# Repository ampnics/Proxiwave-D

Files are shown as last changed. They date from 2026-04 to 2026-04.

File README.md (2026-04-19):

# ProxiWave-D (PWD-v010A)
### Touchless Proximity-Based AC Relay Controller — Open Source Hardware by Ampnics







> An open-source, touchless proximity-based AC relay controller built on ATmega328-A with a VL53L0X Time-of-Flight sensor — designed for contactless switching of 220VAC loads by detecting hand proximity within 10–30mm range.

---

## 📸 Board Preview

| PCB Top View (Sensor Side) | PCB Bottom View (Power Side) |



---


---

## 📋 Table of Contents

- [Overview](#-overview)
- [Features](#-features)
- [How It Works](#-how-it-works)
- [Hardware Specifications](#-hardware-specifications)
- [GPIO Mapping](#-gpio-mapping)
- [Pin Description](#-pin-description)
- [Repository Structure](#-repository-structure)
- [Getting Started](#-getting-started)
- [Firmware Setup](#-firmware-setup)
- [Calibration](#-calibration)
- [Manufacturing](#-manufacturing)
- [Safety Warning](#️-safety-warning)
- [Contributing](#-contributing)
- [Support Us](#-support-us)
- [Connect With Us](#-connect-with-us)
- [License](#-license)

---

## 🔍 Overview

The **ProxiWave-D** is an open-source, touchless proximity relay controller designed for contactless switching of 220VAC loads. It uses a **VL53L0X Time-of-Flight (ToF) distance sensor** to detect hand proximity within a calibrated range of **10mm to 30mm**, triggering an onboard relay to switch AC loads — no physical contact required.

The board runs on **220VAC mains input**, converting it to **5V DC** via an onboard HLK-5M05 power supply module, and further to **3.3V** via an AMS1117-3.3 LDO — powering the ATmega328 and the VL53L0X sensor.

A **backup IR sensor connector (J3)** is also provided for redundancy or alternative sensing modes.

Designed in **KiCad 9.0.1** as part of the open-source hardware series by Ampnics.

---

## ✨ Features

- ✅ Touchless relay switching via VL53L0X ToF proximity sensor
- ✅ ATmega328-A microcontroller (8MHz crystal, 3.3V operation)
- ✅ 220VAC to 5VDC onboard power supply (HLK-5M05)
- ✅ 5V to 3.3V LDO regulator (AMS1117-3.3)
- ✅ SPDT relay for AC load switching
- ✅ MOV surge protection (10D561K)
- ✅ Fuse protection (0.5A / 250VAC)
- ✅ Backup IR sensor connector (J3)
- ✅ Buzzer feedback (MLT-8530)
- ✅ Power LED (Red) + Relay LED (Blue) + Status LED (Green)
- ✅ ICSP / SPI programming port (J2 — 2x3 header)
- ✅ Reset button (SW1)
- ✅ 5x screw terminal AC connector (J1)
- ✅ Test points — 5V, 3V3, GND, AVDD
- ✅ Fiducial markers + 4x mounting holes
- ✅ Sensing area clearly marked on PCB silkscreen
- ✅ Fully open-source — KiCad files included

---

## 🔄 How It Works

```
Hand approaches sensing area (10mm–30mm range)
              │
              ▼
   VL53L0X ToF Sensor detects distance
              │
              ▼
   ATmega328 reads I2C data from sensor
              │
              ▼
   Distance within calibrated threshold?
         ┌────┴────┐
        YES        NO
         │          │
         ▼          ▼
   Relay toggles  No action
   AC load ON/OFF
         │
         ▼
   Buzzer beeps + Status LED updates
```

---

## 🔧 Hardware Specifications

| Parameter | Details |
|---|---|
| Microcontroller | ATmega328-A |
| MCU Clock | 8MHz (External Crystal Y1) |
| MCU Operating Voltage | 3.3V |
| Proximity Sensor | VL53L0X ToF (I2C) |
| Sensor Operating Voltage | 2.6V – 3.6V (3.3V) |
| Detection Range | 10mm – 30mm (calibrated) |
| Input Voltage | 220V AC |
| Power Supply Module | HLK-5M05 (220VAC → 5VDC) |
| LDO Regulator | AMS1117-3.3 (5V → 3.3V) |
| Relay | G5LE-1 (SPDT) |
| Surge Protection | MOV 10D561K |
| Fuse | 0.5A / 250VAC |
| Buzzer | MLT-8530 |
| Status LEDs | Red (Power), Blue (Relay), Green (Status) |
| Programming | ICSP / SPI (J2 — 2x3 header) |
| Backup Sensor Port | J3 — 3-pin connector |
| PCB Tool | KiCad 9.0.1 |
| Board Revision | PWD-v010A |

---

## 📌 GPIO Mapping

| GPIO | Label | Function |
|---|---|---|
| PC1 / A1 | RIN / STS | Status indication |
| PC2 / A2 | RLY | Relay control |
| PC3 / A3 | BUZZER | Buzzer (MLT-8530) |
| PC4 / A4 | SDA | VL53L0X I2C SDA |
| PC5 / A5 | SCL | VL53L0X I2C SCL |
| PD2 / D2 | XSHUT | VL53L0X shutdown pin |
| PD4 / D4 | IR-BKP | Backup IR sensor (J3) |

---

## 🔌 Pin Description

### J1 — AC Screw Terminal (5-pin)

| Pin | Label | Description |
|---|---|---|
| 1 | AC/L | AC Line (Live) input |
| 2 | AC/N | AC Neutral input |
| 3 | NO | Relay Normally Open |
| 4 | C | Relay Common |
| 5 | NC | Relay Normally Closed |

### J2 — ICSP Programming Port (2x3)

| Pin | Label | Description |
|---|---|---|
| 1 | MISO | SPI MISO |
| 2 | VCC | 5V |
| 3 | SCK | SPI Clock |
| 4 | MOSI | SPI MOSI |
| 5 | RST | Reset |
| 6 | GND | Ground |

### J3 — Backup IR Sensor (3-pin)

| Pin | Label | Description |
|---|---|---|
| 1 | SIG | IR sensor signal |
| 2 | GND | Ground |
| 3 | 5V | Power |

### Signal Connector (3-pin)

| Pin | Label | Description |
|---|---|---|
| 1 | SIG | Signal output |
| 2 | GND | Ground |
| 3 | 3V3 | 3.3V output |

---

## 📁 Repository Structure

```
ProxiWave-D/
├── docs/                    # Datasheets and reference documents
├── imgs/                    # PCB renders and product images
├── manufacturing-files/     # Gerbers, BOM, CPL for fabrication
├── schematic/               # KiCad schematic & PCB files
├── ext-3d-models/           # External 3D models for KiCad
├── ext-lib/                 # External KiCad footprints & symbols
└── README.md
```

---

## 🚀 Getting Started

### Prerequisites
- [KiCad 9.0.1](https://www.kicad.org/) — to open schematic and PCB files
- [Arduino IDE](https://www.arduino.cc/en/software) — for firmware
- USBasp / AVRISP programmer — for flashing ATmega328
- [VL53L0X Arduino Library](https://github.com/pololu/vl53l0x-arduino)

### Clone the Repository
```bash
git clone https://github.com/ampnics/Proxiwave-D.git
cd Proxiwave-D
```

---

## 💻 Firmware Setup

### 1. Add ATmega328 (3.3V / 8MHz) Board Support

In Arduino IDE → **Preferences** → Additional Boards Manager URLs → add:
```
https://raw.githubusercontent.com/MCUdude/MiniCore/master/package_MCUdude_MiniCore_index.json
```
Then: **Tools → Board → Boards Manager → search "MiniCore" → Install**

Select these settings:
- Board: `ATmega328`
- Clock: `External 8MHz`
- Voltage: `3.3V`

### 2. Install Required Libraries
```
VL53L0X    → by Pololu
Wire       → built-in
```

### 3. Basic Firmware Structure

```cpp
#include <Wire.h>
#include <VL53L0X.h>

#define RELAY_PIN   A2   // PC2
#define BUZZER_PIN  A3   // PC3
#define XSHUT_PIN   2    // PD2
#define STATUS_PIN  A1   // PC1

#define MIN_RANGE   10   // mm
#define MAX_RANGE   30   // mm

VL53L0X sensor;

void setup() {
  pinMode(RELAY_PIN, OUTPUT);
  pinMode(BUZZER_PIN, OUTPUT);
  pinMode(XSHUT_PIN, OUTPUT);
  pinMode(STATUS_PIN, OUTPUT);

  digitalWrite(XSHUT_PIN, HIGH);
  Wire.begin();
  sensor.init();
  sensor.setTimeout(500);
  sensor.startContinuous();
}

void loop() {
  uint16_t distance = sensor.readRangeContinuousMillimeters();

  if (distance >= MIN_RANGE && distance <= MAX_RANGE) {
    digitalWrite(RELAY_PIN, !digitalRead(RELAY_PIN)); // Toggle relay
    digitalWrite(BUZZER_PIN, HIGH);
    delay(100);
    digitalWrite(BUZZER_PIN, LOW);
    delay(500); // Debounce delay
  }
}
```

### 4. Flash Using USBasp (ICSP)
```
Tools → Programmer → USBasp
Tools → Burn Bootloader (first time only)
Sketch → Upload Using Programmer
```

---

## 🎯 Calibration

> The VL53L0X sensor **must be calibrated** for reliable touchless operation.

- Default detection range: **10mm – 30mm**
- Adjust `MIN_RANGE` and `MAX_RANGE` in firmware based on your enclosure depth
- Mount sensor so the **sensing area circle** marked on PCB silkscreen is fully exposed
- Avoid reflective surfaces directly behind the sensing area
- Test under ambient light conditions before final deployment

---

## 🏭 Manufacturing

Fabrication files are available in `manufacturing-files/`:

- **Gerber files** — for PCB fabrication (JLCPCB / PCBWay)
- **BOM** — Bill of Materials with part numbers
- **CPL** — Component Placement List for SMT assembly

| Parameter | Value |
|---|---|
| Layers | 2 |
| Board Thickness | 1.6mm |
| Copper Weight | 1oz |
| Surface Finish | HASL / ENIG |
| Min Trace Width | 0.2mm |

---

## ⚠️ Safety Warning

> **This board operates at 220V AC mains voltage.**

- ⚠️ Do **NOT** touch the board while connected to mains power
- ⚠️ AC and DC sections are separated on the PCB — always respect this boundary
- ⚠️ Always use proper insulation and an enclosure before deployment
- ⚠️ Fuse (F1 — 0.5A/250VAC) must always be populated
- ⚠️ Intended for use by qualified engineers only

---

## 🤝 Contributing

Contributions are welcome from the community!

1. Fork the repository
2. Create your branch: `git checkout -b feature/your-feature`
3. Commit: `git commit -m "hw: your change"`
4. Push: `git push origin feature/your-feature`
5. Open a **Pull Request**

---

## ☕ Support Us

If this project helped you, consider buying us a coffee!

**[☕ Buy Me a Coffee — Support Ampnics](https://buymeacoffee.com/Ampnics)**

Your support helps us create more open-source hardware for the community!

---

## 🌐 Connect With Us

| Platform | Link |
|---|---|
| 📺 YouTube | [youtube.com/@ampnics](https://youtube.com/@ampnics?si=e0dvaRhfExjZXtJc) |
| 📸 Instagram | [instagram.com/ampnics](https://www.instagram.com/ampnics/) |
| 🐦 X (Twitter) | [twitter.com/ampnics](https://twitter.com/ampnics) |
| 💼 LinkedIn | [linkedin.com/company/ampnics](https://www.linkedin.com/company/ampnics/) |
| 🐙 GitHub | [github.com/ampnics](https://github.com/ampnics) |
| 💬 WhatsApp Community | [Join Here](https://chat.whatsapp.com/HgWOoxyOgLfGEkAPHPM01k) |
| 🌐 Website | [ampnics.com](https://ampnics.com) |

---

## 📄 License

This project is licensed under the **MIT License**.

You are free to use, modify, and distribute this design for personal and commercial purposes with attribution.

---

## 👨‍💻 Designed By

**Md Ammar Maniyar** — [Ampnics](https://github.com/ampnics)

*Engineered in India 🇮🇳*

---

⭐ **Star this repo** if it helped you — it motivates us to release more open-source hardware!

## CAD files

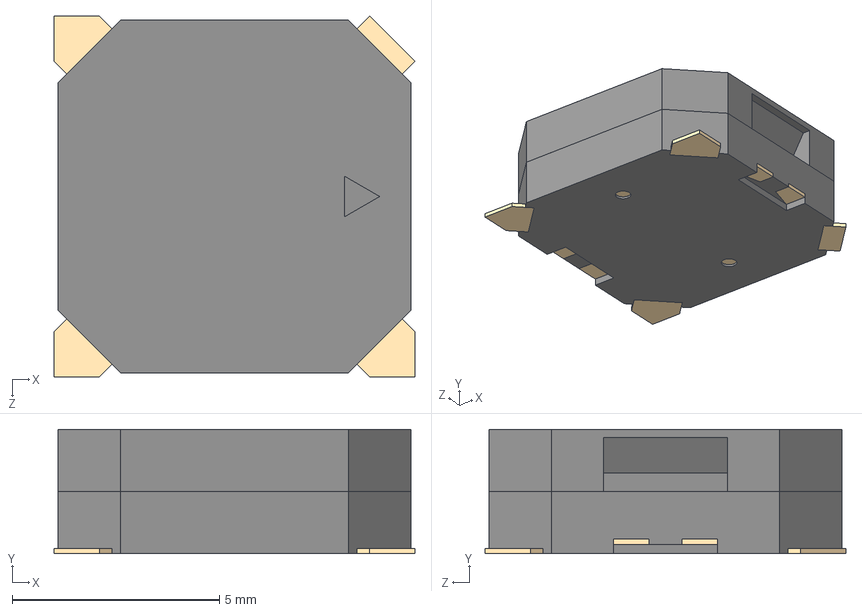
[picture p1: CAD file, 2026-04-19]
Hardware/PWD-v010A/3D-MODELS/MLT-8530--3DModel-STEP-269445.STEP
8.70 x 3.00 x 8.70 mm

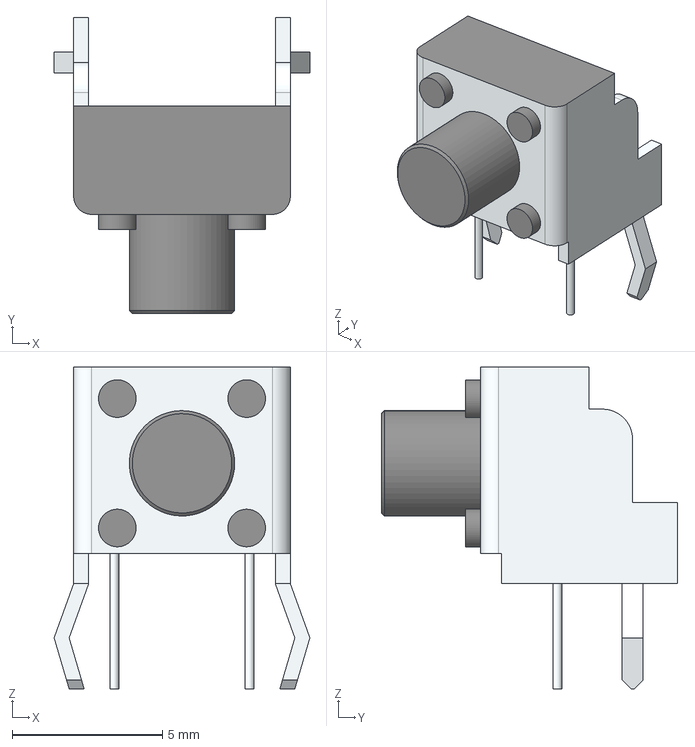
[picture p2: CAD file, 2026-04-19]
Hardware/PWD-v010A/3D-MODELS/SW-DTSA-63K-V.stp
8.50 x 9.85 x 10.7 mm

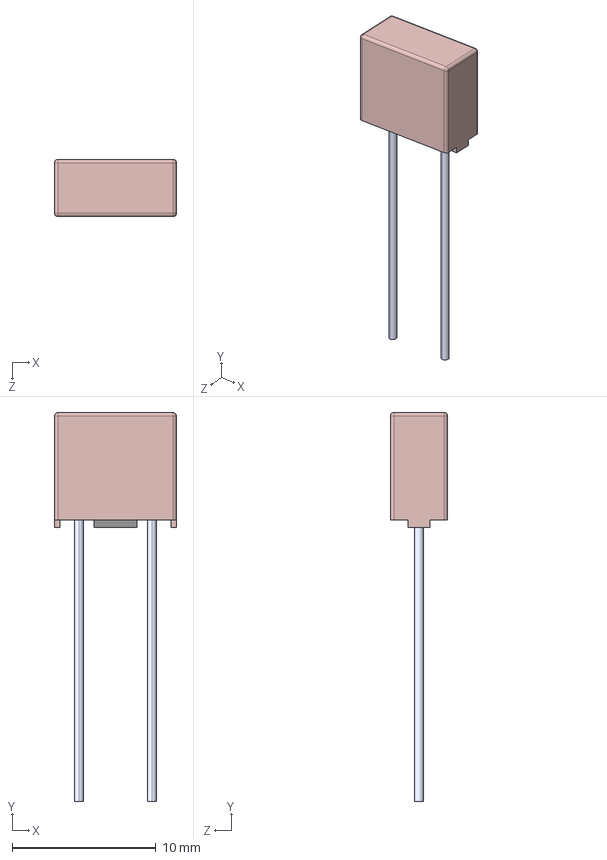
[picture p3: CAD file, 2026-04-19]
Hardware/PWD-v010A/3D-MODELS/39208000000.STEP
8.50 x 27.1 x 4.00 mm

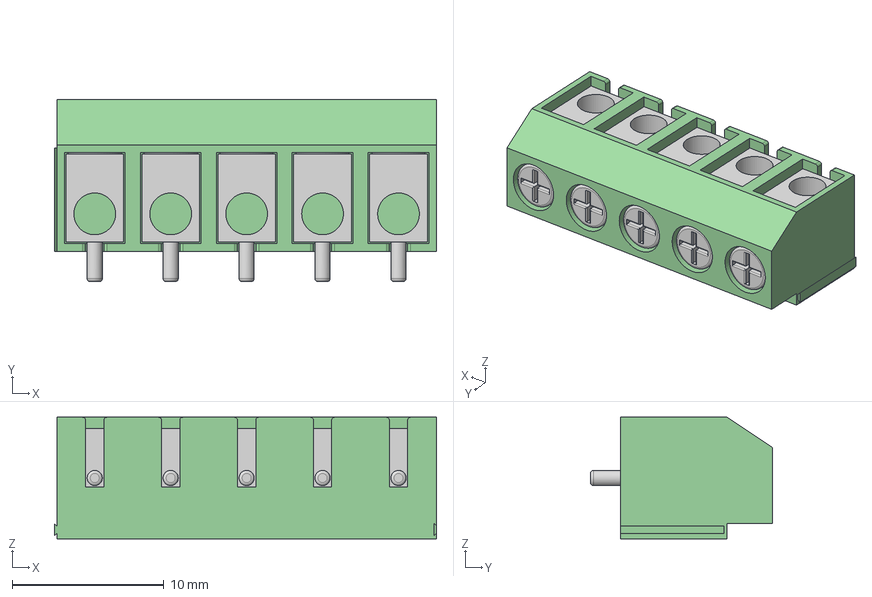
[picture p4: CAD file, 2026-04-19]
Hardware/PWD-v010A/3D-MODELS/Screw Terminal Block 5mm 5-way.step
25.1 x 12.0 x 8.00 mm

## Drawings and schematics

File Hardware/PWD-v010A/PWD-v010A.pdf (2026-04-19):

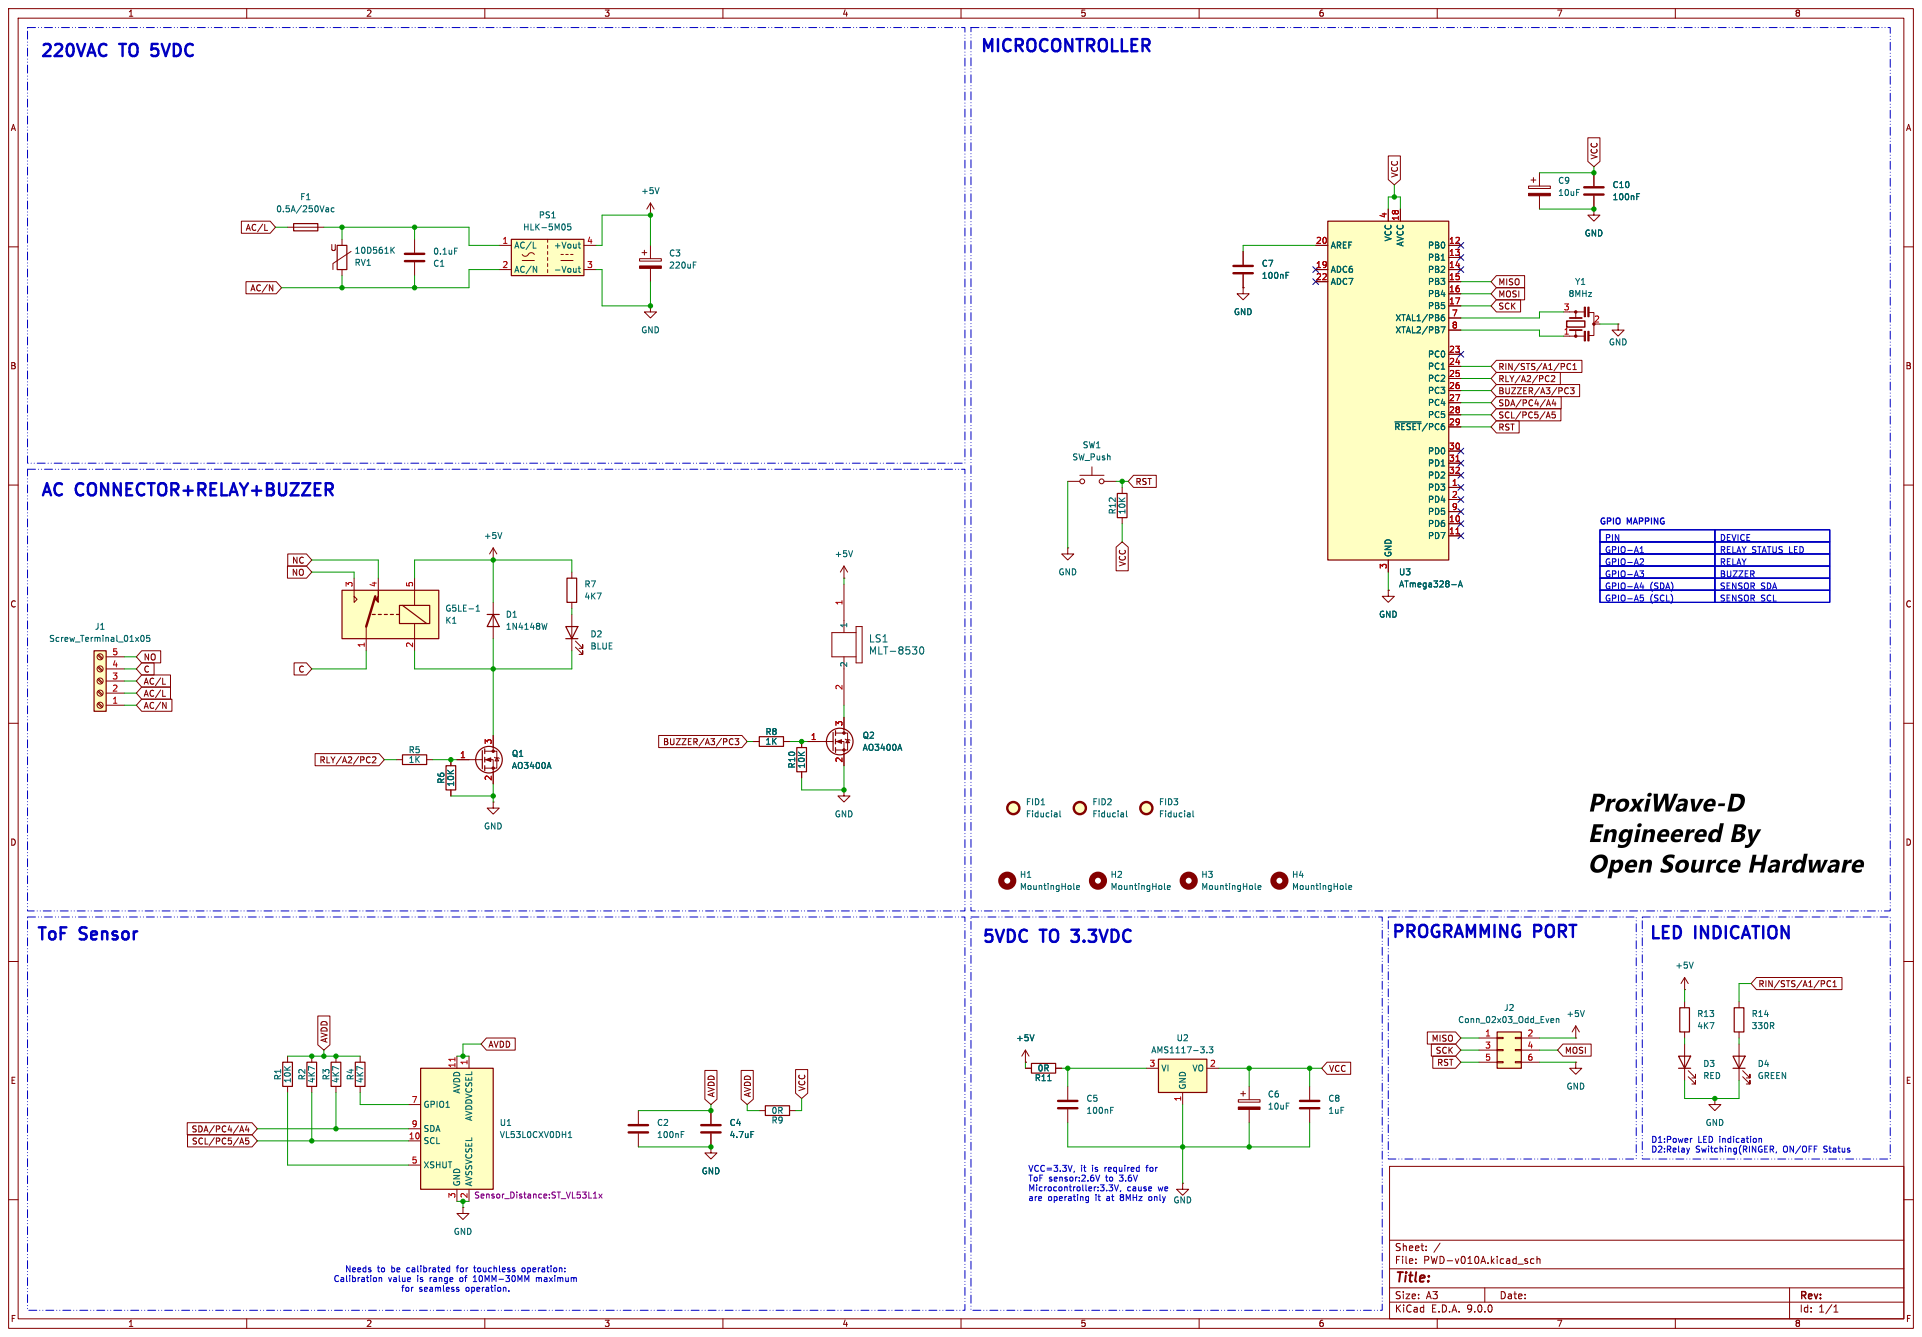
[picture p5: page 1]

3 AVCC 18 PB0 12 PB1 13 PB2 14 PB3 15 PB4 16 PB5 17 XTAL1/PB6 7 XTAL2/PB7 8 PC0 23 PC1 24 PC2 25 PC3 26 PC4 27 PC5 28 ~{RESET}/PC629 PD0 30 PD1 31 PD2 32 PD3 1 PD4 2 PD5 9 PD6 10 PD7 11 U3ATmega328-A GND R10 10K GND

RLY/A2/PC2 SCL/PC5/A5 RST AVDD

AC CONNECTOR+RELAY+BUZZER

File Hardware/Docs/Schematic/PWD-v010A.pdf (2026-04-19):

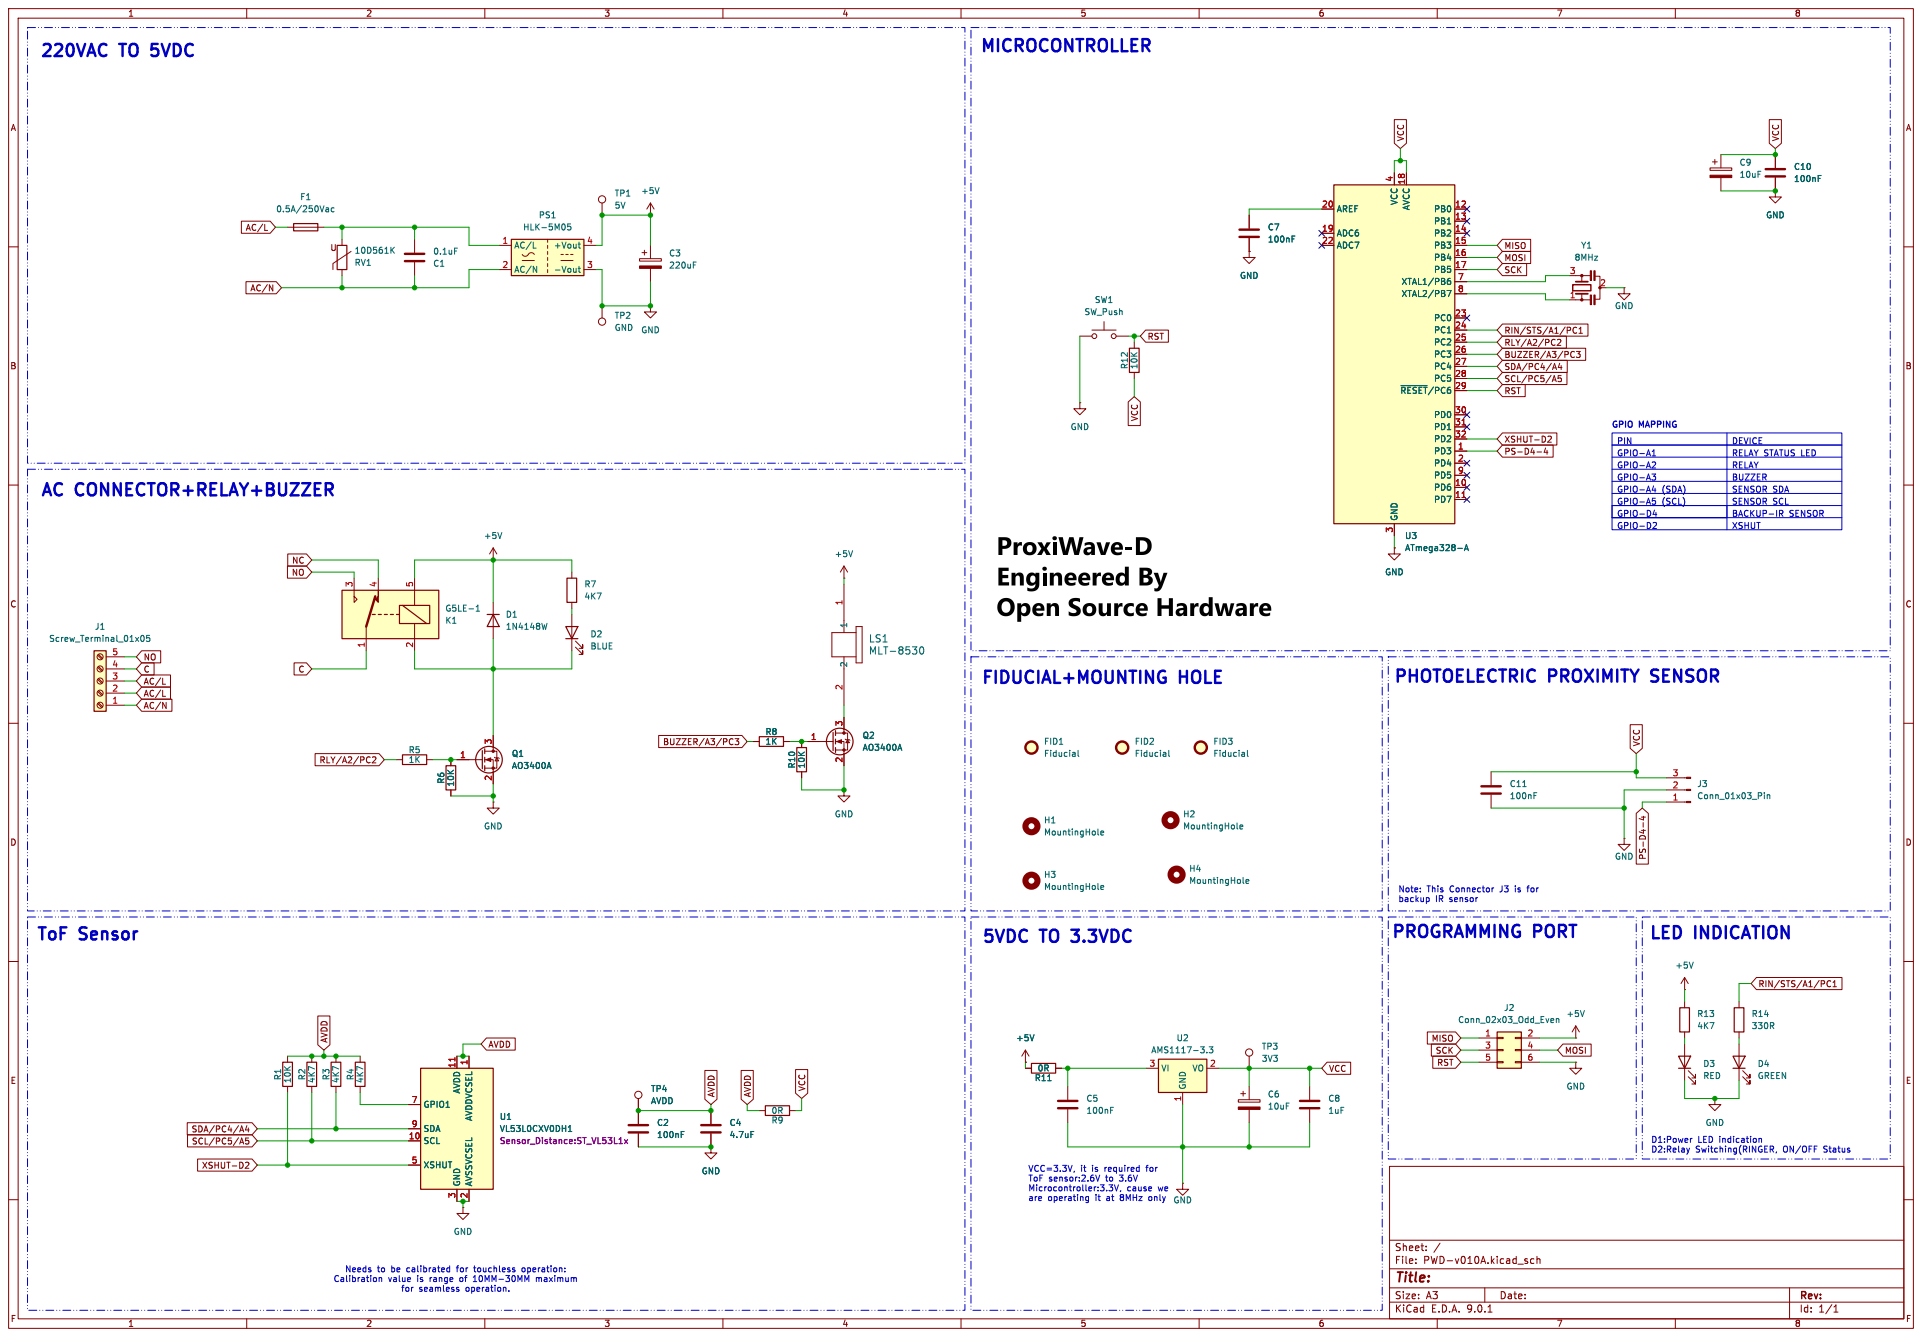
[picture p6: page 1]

GPIO MAPPING AC CONNECTOR+RELAY+BUZZER

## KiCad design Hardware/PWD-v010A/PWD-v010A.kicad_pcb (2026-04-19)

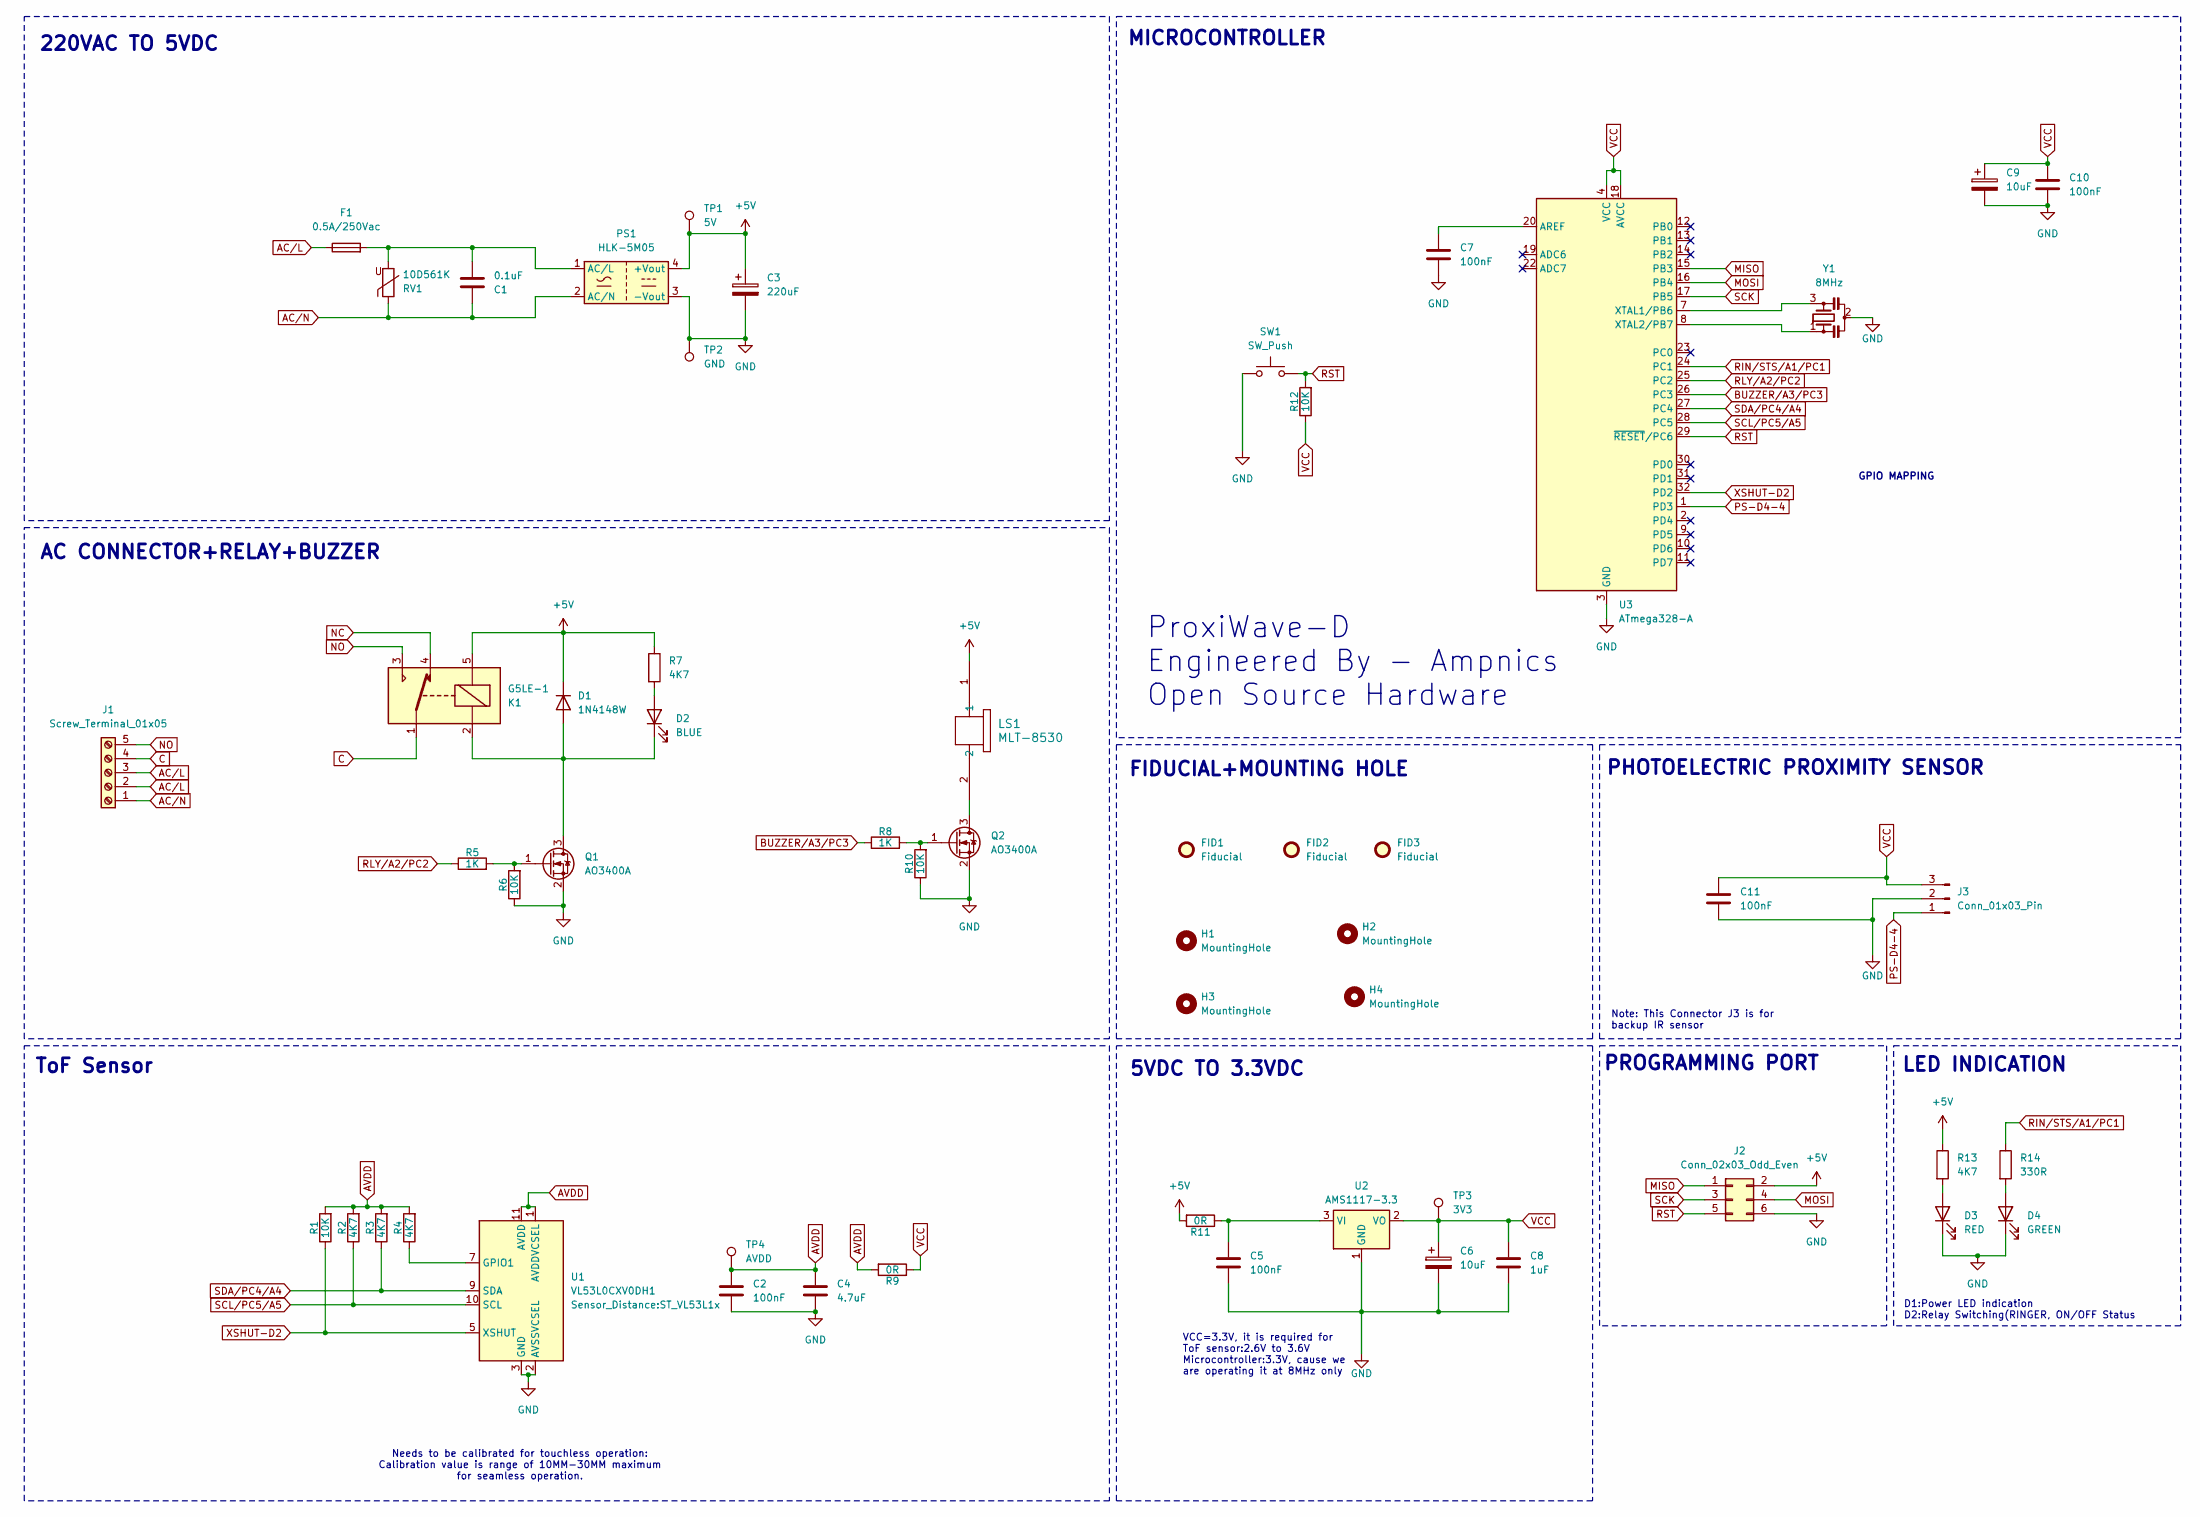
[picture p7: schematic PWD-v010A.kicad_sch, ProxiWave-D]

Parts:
C1: 0.1uF; C_Rect_L13.0mm_W6.0mm_P10.00mm_FKS3_FKP3_MKS4
C2, C5, C7, C10, C11: 100nF; C_0603_1608Metric
C3: 220uF; CP_Elec_8x10
C4: 4.7uF; C_0603_1608Metric
C6, C9: 10uF; CP_EIA-3216-18_Kemet-A
C8: 1uF; C_0603_1608Metric
D1: 1N4148W; D_SOD-123
D2: BLUE; LED_0603_1608Metric
D3: RED; LED_0603_1608Metric
D4: GREEN; LED_0603_1608Metric
F1: 0.5A/250Vac; Fuse_Littelfuse_395Series
FID1, FID2, FID3: Fiducial; Fiducial_0.75mm_Mask1.5mm
H1, H2, H3, H4: MountingHole; MountingHole_2.7mm
J1: Screw_Terminal_01x05; TerminalBlock_bornier-5_P5.08mm
J2: Conn_02x03_Odd_Even; PinHeader_2x03_P2.54mm_Vertical
J3: Conn_01x03_Pin; MPN B3B-XH-A
K1: G5LE-1; Relay_SPDT_Omron-G5LE-1
LS1: MLT-8530; MLT-8530_JHE
PS1: HLK-5M05; Converter_ACDC_Hi-Link_HLK-5Mxx
Q1, Q2: AO3400A; SOT-23
R1, R6, R10, R12: 10K; R_0603_1608Metric
R2, R3, R4, R7, R13: 4K7; R_0603_1608Metric
R5, R8: 1K; R_0603_1608Metric
R9, R11: 0R; R_0603_1608Metric
R14: 330R; R_0603_1608Metric
RV1: 10D561K; RV_Disc_D12mm_W5.8mm_P7.5mm
SW1: SW_Push; SW_Tactile_SKHH_Angled
TP1: 5V; TestPoint_Pad_D1.5mm
TP2: GND; TestPoint_Pad_D1.5mm
TP3: 3V3; TestPoint_Pad_D1.5mm
TP4: AVDD; TestPoint_Pad_D1.5mm
U1: VL53L0CXV0DH1; ST_VL53L1x
U2: AMS1117-3.3; SOT-223-3_TabPin2
U3: ATmega328-A; TQFP-32_7x7mm_P0.8mm
Y1: 8MHz; Resonator_SMD_Murata_CSTxExxV-3Pin_3.0x1.1mm

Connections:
+5V: C3.1, D1.1 (K), J2.2, K1.5, LS1.1, PS1.4 (+Vout), R7.1, R11.2, R13.1, TP1.1
AC/L: F1.1, J1.2, J1.3
AC/N: C1.1, J1.1, PS1.2 (AC/N), RV1.1
AVDD: C2.1, C4.1, R1.2, R2.2, R3.2, R4.2, R9.2, TP4.1, U1.1 (AVDDVCSEL), U1.11 (AVDD)
BUZZER/A3/PC3: R8.1, U3.26 (PC3)
C: J1.4, K1.1
GND: C2.2, C3.2, C4.2, C5.2, C6.2, C7.2, C8.2, C9.2, C10.2, C11.2, D3.1 (K), D4.1 (K), J2.6, J3.2, PS1.3 (-Vout), Q1.2 (S), Q2.2 (S), R6.1, R10.1, SW1.1, TP2.1, U1.2 (AVSSVCSEL), U1.3 (GND), U1.4 (GND), U1.6 (GND), U1.12 (GND), U2.1 (GND), U3.3 (GND), U3.5 (GND), U3.21 (GND), Y1.2
MISO: J2.1, U3.15 (PB3)
MOSI: J2.4, U3.16 (PB4)
NC: K1.4
NO: J1.5, K1.3
unnamed: D1.2 (A), D2.1 (K), K1.2, Q1.3 (D)
unnamed: D2.2 (A), R7.2
unnamed: D3.2 (A), R13.2
unnamed: D4.2 (A), R14.2
unnamed: C1.2, F1.2, PS1.1 (AC/L), RV1.2
unnamed: Q1.1 (G), R5.2, R6.2
unnamed: LS1.2, Q2.3 (D)
unnamed: Q2.1 (G), R8.2, R10.2
unnamed: R4.1, U1.7 (GPIO1)
unnamed: C5.1, R11.1, U2.3 (VI)
unnamed: C7.1, U3.20 (AREF)
unnamed: U3.7 (XTAL1/PB6), Y1.3
unnamed: U3.8 (XTAL2/PB7), Y1.1
PS-D4-4: J3.1, U3.1 (PD3)
RIN/STS/A1/PC1: R14.1, U3.24 (PC1)
RLY/A2/PC2: R5.1, U3.25 (PC2)
RST: J2.5, R12.2, SW1.2, U3.29 (~RESET/PC6)
SCK: J2.3, U3.17 (PB5)
SCL/PC5/A5: R2.1, U1.10 (SCL), U3.28 (PC5)
SDA/PC4/A4: R3.1, U1.9 (SDA), U3.27 (PC4)
VCC: C6.1, C8.1, C9.1, C10.1, C11.1, J3.3, R9.1, R12.1, TP3.1, U2.2 (VO), U3.4 (VCC), U3.6 (VCC), U3.18 (AVCC)
XSHUT-D2: R1.1, U1.5 (XSHUT), U3.32 (PD2)

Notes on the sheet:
VCC=3.3V, it is required for ToF sensor:2.6V to 3.6V Microcontroller:3.3V, cause we are operating it at 8MHz only
220VAC TO 5VDC
ToF Sensor
PHOTOELECTRIC PROXIMITY SENSOR
MICROCONTROLLER
ProxiWave-D Engineered By - Ampnics Open Source Hardware
5VDC TO 3.3VDC
Note: This Connector J3 is for backup IR sensor
GPIO MAPPING
PROGRAMMING PORT
AC CONNECTOR+RELAY+BUZZER
LED INDICATION
FIDUCIAL+MOUNTING HOLE
D1:Power LED indication D2:Relay Switching(RINGER, ON/OFF Status
Needs to be calibrated for touchless operation: Calibration value is range of 10MM-30MM maximum for seamless operation.

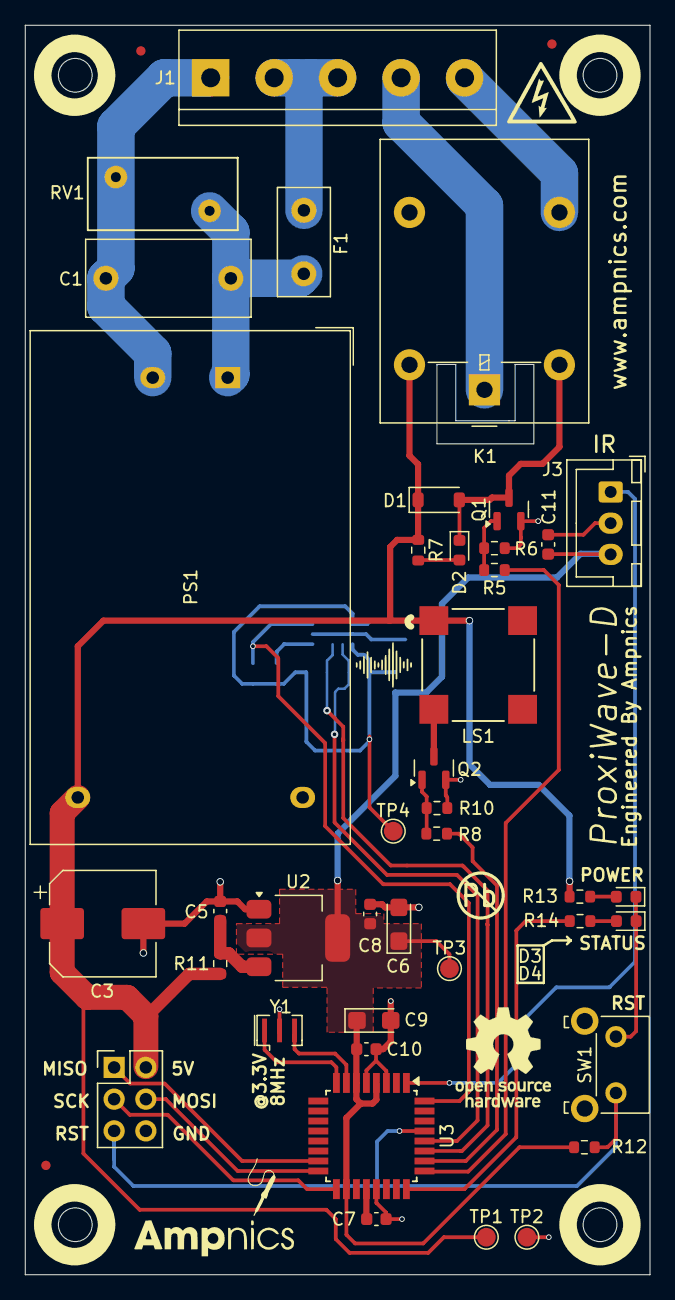
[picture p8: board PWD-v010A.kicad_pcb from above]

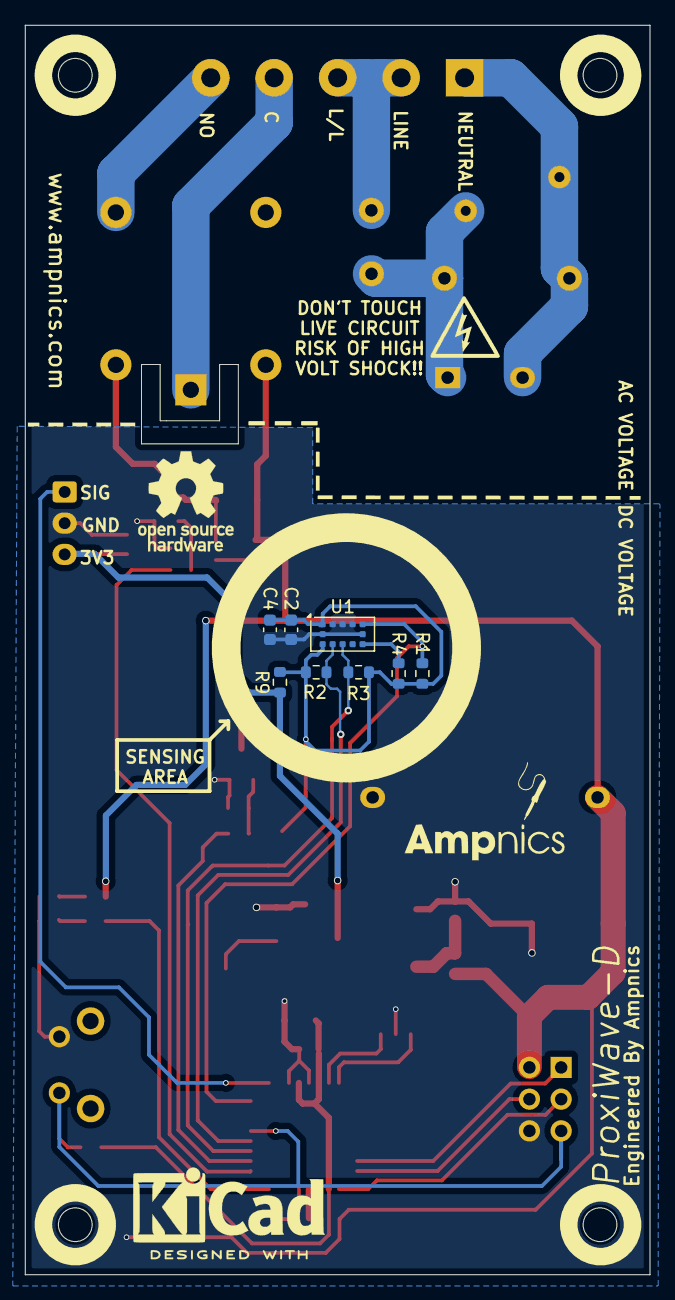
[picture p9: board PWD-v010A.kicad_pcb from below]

Board: 2 copper layers, 50.0 x 100.0 mm, 56 parts (8 on the bottom side), 32 nets.

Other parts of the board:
Sign-PbFree: LOGO_PBFREE

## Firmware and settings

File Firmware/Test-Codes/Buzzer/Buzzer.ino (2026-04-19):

/***********************************************************************
 * Engineered by : Ampnics
 * Project       : ProxiWave-D
 * Version       : v0.1.0
 * Date          : Dec 2025
 * Author        : Md Ammar Maniyar
 *
 * Test Name     : Buzzer Functional Test
 * Description   : Verifies buzzer driver circuit using GPIO and PWM.
 * MCU           : ATmega328P @ 3.3V, 8MHz
 *
 * GPIO Mapping  :
 *   BUZZER  -> PC3 (A3)
 *
 * Test Method   :
 *   - Generates a 2kHz tone for 300 ms
 *   - Silence for 700 ms
 *   - Repeats continuously
 *
 * Expected Result:
 *   - Audible beep once every second
 ***********************************************************************/

#define BUZZER_PIN A3

void setup() {
  pinMode(BUZZER_PIN, OUTPUT);
}

void loop() {
  tone(BUZZER_PIN, 2000);   // 2 kHz tone
  delay(300);

  noTone(BUZZER_PIN);       // Stop buzzer
  delay(700);
}

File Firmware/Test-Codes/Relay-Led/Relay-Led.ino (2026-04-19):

/***********************************************************************
 * Engineered by : Ampnics
 * Project       : ProxiWave-D
 * Version       : v0.1.0
 * Date          : Dec 2025
 * Author        : Md Ammar Maniyar
 *
 * Test Name     : Relay Status LED Test
 * Description   : Verifies relay status LED polarity and resistor value.
 * MCU           : ATmega328P @ 3.3V, 8MHz
 *
 * GPIO Mapping  :
 *   RELAY_LED -> PC1 (A1)
 *
 * Test Method   :
 *   - LED ON for 500 ms
 *   - LED OFF for 500 ms
 *
 * Expected Result:
 *   - LED blinks at ~1 Hz
 ***********************************************************************/

#define RELAY_LED_PIN A1

void setup() {
  pinMode(RELAY_LED_PIN, OUTPUT);
}

void loop() {
  digitalWrite(RELAY_LED_PIN, HIGH);
  delay(500);

  digitalWrite(RELAY_LED_PIN, LOW);
  delay(500);
}

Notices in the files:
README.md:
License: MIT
